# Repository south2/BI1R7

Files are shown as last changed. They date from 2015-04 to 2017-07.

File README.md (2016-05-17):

# body interaction vibrator development board

body interaction 1 board, revision 7

The *body interaction 1* is a tiny microcontroller board for building vibrating devices like (sex) toys. 
The vibration strength is controlled by motion. It is equipped with a radio module for wireless data transmission. 
The *body interaction 1* includes a LiPo battery and a capsuled vibration motor. 
Supports the Arduino IDE and Codebender.

*body interaction 1* is small, cheap and you can start at once. You can program the board with the Arduino software (IDE) or in a web browser (eg. codebender). A demo sketch is already uploaded to the board. Download 3D cases from [Thingiverse](http://www.thingiverse.com), print them, assemble the *body interaction 1* and have fun! Or invent your own toy using 3d modelling software.

#### More technical staff
*body interaction 1* has a Atmel Attiny84 on board, a LiPo charger (via USB) and a LiPo battery. The encapsuled vibration motor is controlled with PWM, though you can vary the vibration strength as needed. There are two additional I/O ports which can be used for other sensors or actuators. Programming is done with an ISP interface (2×3 pole header). The board has BMA020 accelerometer and a RFM12B (915 or 868 Mhz) radio module. Size: approx. 20x36mm. Open Source Hardware. Supports the Arduino IDE as well as codebender.
You need an ISP programmer (eg. USB tiny ISP) for uploading *new* programs (sketches) to the *body interaction 1*. There are two options for the wireless transmission chip. You can select 868 MHz (EU) or 915MHz (US, Australia) radio module.

Blog & How-to's: [www.bodyinteraction.com](http://www.bodyinteraction.com)

Download the [Quick start guide](https://projectbodyinteraction.files.wordpress.com/2015/09/quickstartguide-bodyinteraction1.pdf)

3d models at [Thingiverse](http://www.thingiverse.com/south/designs)

Construct your own with the 3d modelling software [Tinkercad](https://www.tinkercad.com/users/3N2Od7pDF0x-bodyinteraction)

Arduino example sketch at [codebender](https://codebender.cc/embed/sketch:96042#p5_fin.ino)

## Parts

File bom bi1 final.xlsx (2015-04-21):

Partlist
2015-03-27 | BI1R7.zip
Part | Value | Device | Package | Description (Package size in inch) | Ordered from | Order-ID | Manufacturer Part No | Remarks
BMA020 |  | BMA020 | LBA-12 | BOSCH033 (BMA020) mobile phone chips gravity acceleration sensor | Aliexpress |  |  | ordered via aliexpress | http://www.aliexpress.com/snapshot/285585944.html
C1 | 0.1micro | C-EUC0603K | C0603K | Multilayer Ceramic Capacitors MLCC - SMD/SMT 0201 0.1pF 25volts C0G +/-0.1pF | Mouser | 81-GRM0335C1ER10BA1D | GRM0335C1ER10BA01D |  | http://de.mouser.com/ProductDetail/Murata/GRM0335C1ER10BA01D/
C2 | 0.1micro | C-EUC0603K | C0603K | Multilayer Ceramic Capacitors MLCC - SMD/SMT 0201 0.1pF 25volts C0G +/-0.1pF | Mouser | 81-GRM0335C1ER10BA1D | GRM0335C1ER10BA01D |  | http://de.mouser.com/ProductDetail/Murata/GRM0335C1ER10BA01D/
C3 | 1micro | CAP0603-CAP | 0603-CAP | Multilayer Ceramic Capacitors MLCC - SMD/SMT CAP, MLCC, 0201, 50V C0G 1pF 0.25pF tol | Mouser | 963-UMK063CG010CT-F | UMK063CG010CT-F |  | http://de.mouser.com/ProductDetail/Taiyo-Yuden/UMK063CG010CT-F/
C4 | 1micro | CAP0603-CAP | 0603-CAP | Multilayer Ceramic Capacitors MLCC - SMD/SMT CAP, MLCC, 0201, 50V C0G 1pF 0.25pF tol | Mouser | 963-UMK063CG010CT-F | UMK063CG010CT-F |  | http://de.mouser.com/ProductDetail/Taiyo-Yuden/UMK063CG010CT-F/
C7 | 0.1micro | CAP0603-CAP | 0603-CAP | Multilayer Ceramic Capacitors MLCC - SMD/SMT 0201 0.1pF 25volts C0G +/-0.1pF | Mouser | 81-GRM0335C1ER10BA1D | GRM0335C1ER10BA01D |  | http://de.mouser.com/ProductDetail/Murata/GRM0335C1ER10BA01D/
LED/CHARGE | ORANGE | LED0603 | LED-0603 | Standard LEDs - SMD GaP Orange | Mouser | 630-HSMD-C190 | HSMD-C190 |  | http://de.mouser.com/ProductDetail/Avago-Technologies/HSMD-C190/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
MICROCONTROLLER | Attiny84 | TINY24/44/84-SSU | SOIC14 | 8-bit Microcontrollers - MCU 8-bit 512B SRAM 20MHz 2.7-5.5V | Mouser | 556-ATTINY84-20SSU | ATTINY84-20SSU |  | http://de.mouser.com/Search/ProductDetail.aspx
MBR120* | F | MBR120ESF | SOD-123_MINI-SMA | Schottky Diodes & Rectifiers 1A 20V | Mouser | 863-MBR120ESFT1G (https://de.mouser.com/Search/ProductDetail.aspx) | MBR120ESFT1G (https://de.mouser.com/Search/ProductDetail.aspx)
M*1N02 |  | MGSF1N02LT1G | SOT23 | MOSFET N-CH 20V 750MA SOT23 (Transistor) | digikey | MGSF1N02LT1GOSCT-ND | MGSF1N02LT1G (http://www.digikey.de/product-detail/en/MGSF1N02LT1G/MGSF1N02LT1GOSTR-ND/919442) |  | http://de.mouser.com/Search/ProductDetail.aspx
R1 | 10K | R-EU_R0603 | R0603 | Thick Film Resistors - SMD 1/10watts 10Kohms 1% | Mouser | 660-RK73H1JTTD1002F | RK73H1JTTD1002F |  | https://de.mouser.com/Search/ProductDetail.aspx
R2 | 10K | R-EU_R0603 | R0603 | Thick Film Resistors - SMD 1/10watts 10Kohms 1% | Mouser | 660-RK73H1JTTD1002F | RK73H1JTTD1002F |  | https://de.mouser.com/Search/ProductDetail.aspx
R4 | 15 | R-EU_R0603 | R0603 | Thick Film Resistors - SMD 1/10watts 15ohms 1% | Mouser | 660-RK73H1JTTDD15R0F | RK73H1JTTDD15R0F |  | https://de.mouser.com/Search/ProductDetail.aspx
R6 | 50k | R-EU_R0603 | R0603 | Thick Film Resistors - SMD 1/10watts 49.9Kohms | Mouser | 660-RK73H1JTTD4992F | RK73H1JTTD4992F |  | https://de.mouser.com/Search/ProductDetail.aspx
R9 | 470 | R-US_R0603 | R0603 | Thick Film Resistors - SMD 0603 470ohms 5% Tol | Mouser | 667-ERJ-3GEYJ471V | ERJ-3GEYJ471V |  | https://de.mouser.com/Search/ProductDetail.aspx
RFM12B - RF module the 868 MHz (70x) or 915 MHz (30x) versions will be soldered on the bottom side |  |  |  | octamex | FM-RFM12B-868-S1 | RFM12B-868-S1 | 868 MHz for Europe, select S1 or S2 type, both are ok
 |  |  |  | Sparcfun | WRL-12031 |  | 915 MHz for US and Australia, select S1 or S2 type, both are ok | https://www.sparkfun.com/products/12031
SWITCH | ON | SWITCH-SPDTSMD2 | SWITCH-SPDT-SMD | SWITCH SLIDE SPDT 12V 100MA GW | digikey | 401-2012-1-ND | AYZ0102AGRLC (http://www.digikey.de/product-detail/en/AYZ0102AGRLC/401-2012-2-ND/1640108) |  | http://de.mouser.com/Search/ProductDetail.aspx
U2 | MAX | MAX1555 | SOT23-5 | Battery Management Dual USB/AC 1-Cell Li+ Battery Charger | Mouser | 700-MAX1555EZK+T | MAX1555EZK+T |  | http://de.mouser.com/Search/ProductDetail.aspx
USB |  | USB-MICROB | USB-MICROB | USB Connectors MICRO B RECEPT RA SMT BTTM MNT | Mouser | 798-ZX62-B-5PA11 | ZX62-B-5PA(11) |  | https://de.mouser.com/Search/ProductDetail.aspx
LiPo connection on board |  |  |  | JST CONN HEADER SH 2POS SIDE 1MM TIN | digikey | 455-1802-1-ND
LiPo JST SH Connector | please connect LiPo cables with JST SH connector (2 crimp terminals and housing) |  |  | CONN HOUSING SH 2POS 1MM WHITE | digikey | 455-1392-ND
 |  |  |  | CONN TERM SH CRIMP 28-32AWG TIN | digikey | 455-1561-1-ND
LiPo
Motor connection on board |  |  |  | JST CONN HEADER SH 2POS SIDE 1MM TIN | digikey | 455-1802-1-ND
motor JST SH Connector | please connect motor cables with JST SH connector (2 crimp terminals and housing) |  |  | CONN HOUSING SH 2POS 1MM WHITE | digikey | 455-1392-ND
 |  |  |  | CONN TERM SH CRIMP 28-32AWG TIN | digikey | 455-1561-1-ND
Motor |  |  |  | 7mm 1.5V Vibration motor |  | 306-108 |  |  | https://catalog.precisionmicrodrives.com/order-parts/product/306-108-7mm-vibration-motor-25mm-type
ISP Connector - do NOT solder
ISP |  | MA03-2S | MA03-2-0.8 | CONN HEADER 6POS .100 R/A 15AU | digikey | 609-3343-ND | 68021-206HLF |  | http://www.digikey.com/product-search/en?WT.z_header=search_go&lang=en&site=us&x=0&y=0&formaction=on

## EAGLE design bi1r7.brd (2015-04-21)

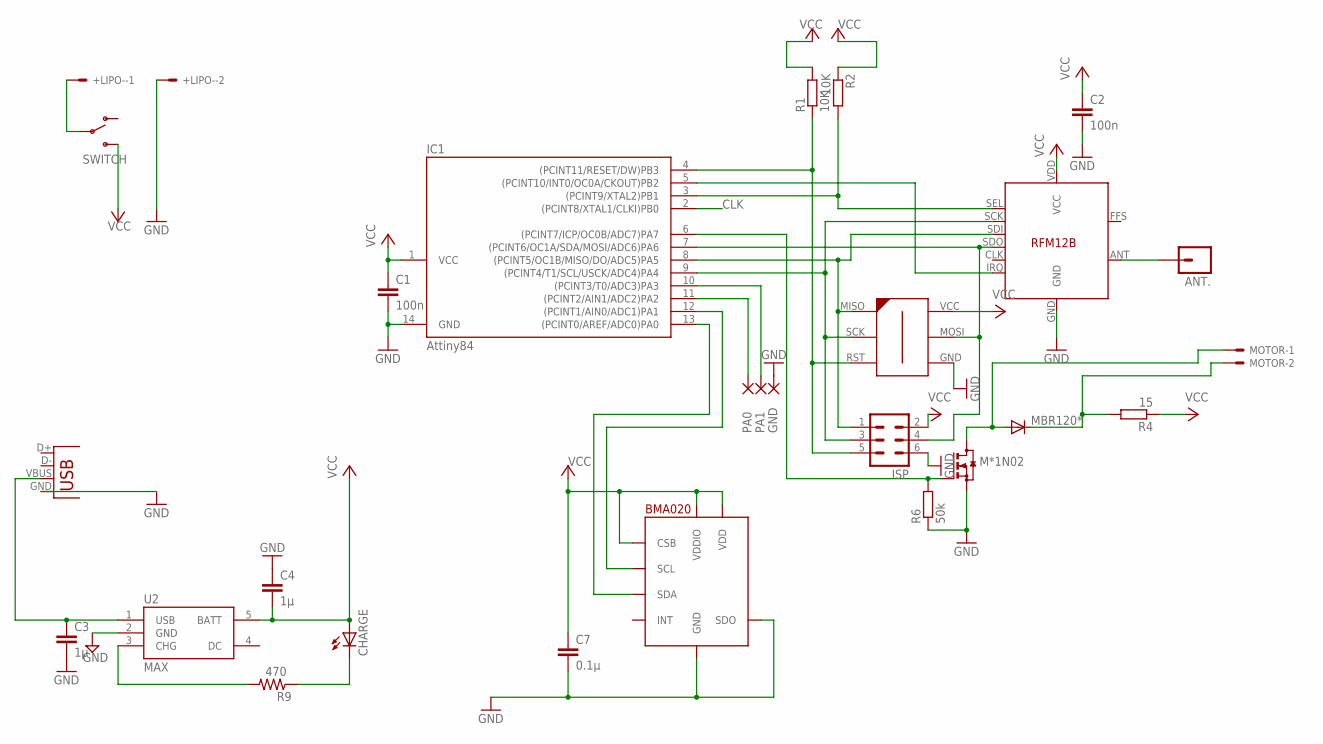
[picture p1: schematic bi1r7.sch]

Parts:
+LIPO-: SM02B-SRSS-TB
ANT.: M01PTH; 1X01
BMA020: BMA020; LBA-12
C1, C2: 100n; C0603K
C3, C4: 1µ; 0603-CAP
C7: 0.1µ; 0603-CAP
CHARGE: LED0603; LED-0603
GND: SMD2; SMD1,27-2,54
IC1: Attiny84; SOIC14
ISP: MA03-2S; MA03-2-0.8
M*1N02: BSS123; SOT23
MBR120*: CGRM4001-G; SOD-123_MINI-SMA
MOTOR: SM02B-SRSS-TB
PA0, PA1: SMD2; SMD1,27-2,54
R1, R2: 10K; R0603
R4: 15; R0603
R6: 50k; R0603
R9: 470; R0603
RFM12B: RFM12B
SWITCH: SWITCH-SPDTSMD2; SWITCH-SPDT-SMD
U2: MAX; SOT23-5
U$2: AVR-ISP-6-EDGE; 6PAD_ISP
USB: USB-MICROB

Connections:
CLK: IC1.2 ((PCINT8/XTAL1/CLKI)PB0)
GND: +LIPO-.2, BMA020.P$3 (GND), BMA020.P$7 (SDO), C1.2, C2.2, C3.2, C4.1, C7.2, GND.1, IC1.14 (GND), ISP.6, M*1N02.2 (S), R6.1, RFM12B.GND, U2.2 (GND), U$2.GND, USB.GND
LED: BMA020.P$8 (SDA), IC1.13 ((PCINT0/AREF/ADC0)PA0)
unnamed: IC1.4 ((PCINT11/RESET/DW)PB3), ISP.5, R1.1, U$2.RST
unnamed: IC1.3 ((PCINT9/XTAL2)PB1), R2.2, RFM12B.SEL
unnamed: ANT..1, RFM12B.ANT
unnamed: IC1.9 ((PCINT4/T1/SCL/USCK/ADC4)PA4), ISP.3, RFM12B.SCK, U$2.SCK
unnamed: IC1.8 ((PCINT5/OC1B/MISO/DO/ADC5)PA5), ISP.1, RFM12B.SDI, U$2.MISO
unnamed: IC1.7 ((PCINT6/OC1A/SDA/MOSI/ADC6)PA6), ISP.4, RFM12B.SDO, U$2.MOSI
unnamed: IC1.5 ((PCINT10/INT0/OC0A/CKOUT)PB2), RFM12B.IRQ
unnamed: IC1.6 ((PCINT7/ICP/OC0B/ADC7)PA7), M*1N02.1 (G), R6.2
unnamed: IC1.10 ((PCINT3/T0/ADC3)PA3), PA1.1
unnamed: IC1.11 ((PCINT2/AIN1/ADC2)PA2), PA0.1
unnamed: BMA020.P$6 (SCL), IC1.12 ((PCINT1/AIN0/ADC1)PA1)
unnamed: M*1N02.3 (D), MBR120*.A, MOTOR.1
unnamed: MBR120*.C, MOTOR.2, R4.2
unnamed: C3.1, U2.1 (USB), USB.VBUS
unnamed: +LIPO-.1, SWITCH.2
unnamed: CHARGE.C, R9.1
unnamed: R9.2, U2.3 (CHG)
VCC: BMA020.P$2 (VDD), BMA020.P$5 (CSB), BMA020.P$9 (VDDIO), C1.1, C2.1, C4.2, C7.1, CHARGE.A, IC1.1 (VCC), ISP.2, R1.2, R2.1, R4.1, RFM12B.VDD (VCC), SWITCH.3 (S), U2.5 (BATT), U$2.VCC

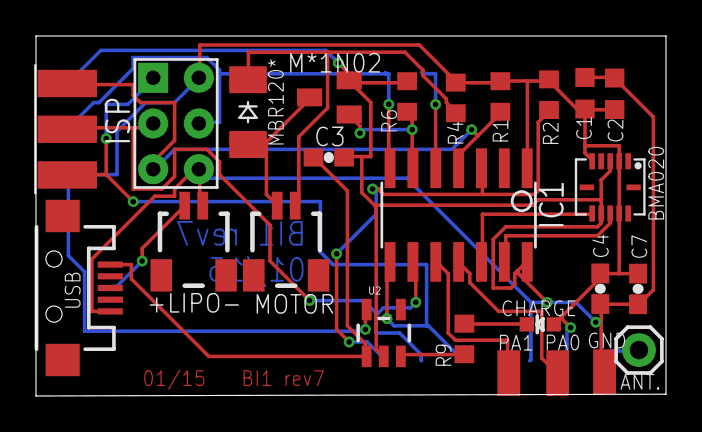
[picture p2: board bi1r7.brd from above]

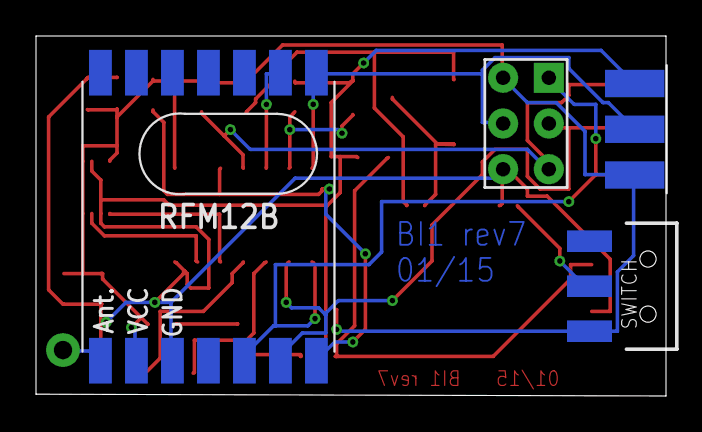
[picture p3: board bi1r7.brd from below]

Board: 4 copper layers, 35.0 x 20.0 mm, 27 parts (2 on the bottom side), 20 nets.

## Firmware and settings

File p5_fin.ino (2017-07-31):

/* body interaction 1 script "p5"
   hardware: body interaction 1 board
   www.bodyinteraction.com
   info@bodyinteraction.com

   The body interaction 1 board is based on the Jeenode Micro that uses for the communication the Hope RFM12b. In the context
   of wireless communication each body interaction board is a node.
   Motion is measured with the accelerometer BMA020. A vibration motor is driven with a simple  with transitor and diode.

   The script reads data from the accelorometer. Depending of the measured motion a vibration motor is speed up or slowed
   down. (Slow motion = reduce viration motor speed, fast motion = speed up). When the measured motion changes the motion data are send out and can be received by other BI1. In addition you can
   use a jeenode to receive the data and send them to a PC for further processing.
   At the same time this script listen to other body interaction boards which send their motion data
   to all listening nodes. When the measured motion of other body interaction board are different from the motion
   measured by this script, the vibration motor is adjusted (speed up or slowed down). So two or more body interaction boards
   can influence each other and syncronize after some time.

   There are 3 states (modes): active, pause, sleep

   active: In the active state the body interaction board behave like described above. When there is no motion and other boards don't
   send motion data the vibration motor is set to low vibration. After some time the state changes to pause.

   pause: In the pause state the vibration motor is off. But the body interaction board still listen to other body interaction board.
   If it receives motion data from an other board or wehn to motion of the borad itself changes the state is changed to active.
   If nothing happens the state is changes to sleeping after some time.

   sleeping: The body interaction board is set to sleep modus and saves battery power. After some tiem the board wakes up
   and read out the motion data. If the board is moved the state is changed to active.

   This code is in the public domain.
  */
#include <JeeLib.h> // Jeelab Library
#include <avr/sleep.h> // sleep module
ISR(WDT_vect)
{
	Sleepy::watchdogEvent();
}

// states
const int active = 2;
const int pause = 1;
const int sleeping = 0;
int state = active; // current state

const int myId = 3; //Id number of this node
const int myNetwork = 20; // number of the network, only nodes in the same network can communicate with one another

// constants are compared with calcDiff()
const int sensorNoise = 20;
const int diffLowSpeed = 35; //v1: 70
const int maxMotorSpeed = 255; //255
const int decreaseStep = 20; //v1: 20
const int wakeUpDiff = 20; //wake up from sleep state
const int motorPin = 3;  // pin number for driving the node with PWM

const int sendMax = 8;
const int sendNormal = 3;

PortI2C myBus (1); // the accelerometer is connected with I2C port number 1 (ports are a convention in the JeeLib)

GravityPlug sensor (myBus); // the accelerometer is named as "sensor"

// Jeelib timer
MilliTimer sendTimer; // sending data is allowed when timer fires
MilliTimer readGTimer; // when timer fires gravity (motion) data should be read
MilliTimer pauseTimer; // when timer fires BI1 board can go into state pause
MilliTimer sleepTimer; // when timer fires BI1 board can go into stat sleep

int payload[] = {diffLowSpeed, state}; // payload is an array send to other BI1

//global variables
int p1[3] = {0, 0, 0}; // Motion data and time=1 in (x,y,z) direction
int p0[3] = {0, 0, 0}; // Motion data and time=0 in (x,y,z) direction
int d[3] = {0, 0, 0}; // differnce between time=1 and time=0 in (x,y,z) direction

// character to integer casting
int c2i(char c)
{
	return (((int)c) + 127);
}
// integer to character casting
char i2c (int i)
{
	return ((char)i - 127);
}

// heuristic function for calculating the motion difference between time=1 and time=0
// returns the maximum difference from each (x,y,z) direction
int calcDiff()
{
	int diff;
	d[0] = abs(p1[0] - p0[0]);
	d[1] = abs(p1[1] - p0[1]);
	d[2] = abs(p1[2] - p0[2]);
	diff = max(d[0], d[1]);
	diff = max(diff, d[2]);
	return diff;
}

// read out the acceleromter data
// function return the difference based on calcdiff()
int gravityRead ()
{
	const int* p = sensor.getAxes();
	int difference;
	p0[0] = p1[0]; // store old data in p0[] (time = 0)
	p0[1] = p1[1];
	p0[2] = p1[2];
	p = sensor.getAxes(); // read out sensor
	p1[0] = p[0]; // store new data in p1[] (time = 1)
	p1[1] = p[1];
	p1[2] = p[2];
	difference = calcDiff();
	return difference;
}


boolean shouldSend()   // interval between data sending
{
	sendTimer.poll(100); // 100 millisecond = 0.1 second (1 second = 1000 milliseconds)
}
boolean shouldReadG()   // intervall between motion measurement
{
	readGTimer.poll(300); // approx 0.3 seconds
}
void resetReadGTimer()   // reset timer
{
	readGTimer.set(0);
}
boolean shouldPause()  // interval between last measured motion change and changing state to pause (motor off)
{
	pauseTimer.poll();
}
boolean armPauseTimer()  // init timer
{
	pauseTimer.set(1000 * 5 * 2); // aprox 10 seconds
}
boolean shouldSleep()   // interval between entering pause state and changing to sleep state
{
	sleepTimer.poll();
}
void armSleepTimer()   // init timer
{
	sleepTimer.set(1000 * 5 * 4); // approx 10 seconds
}



int diff_t0; // last measured difference in motion
int diff; // variable for current difference in motion

int repeatSendN; // repeat data send n times
boolean received; // boolean variable true when data received

/* in this loop the following tasks are done:
   1. measure motion data
   2. change vibration motor speed according to motion data
   3. change states
   4. listen to the receiver
   5. change vibration motor speed if motion data from othe body interaction 1 (BI1) are received
*/

void loop()
{
	if (shouldReadG())
	{
		diff = gravityRead(); //measure motion data
		if (state == pause && diff < diffLowSpeed) diff = 0; // set variable diff to 0 when in pause state
		else   // motion detected: calculated diff, smoothing
		{
			if (diff + decreaseStep < diff_t0)
			{
				diff = max(diff_t0 - decreaseStep, diffLowSpeed);    // motion reduced
				state = active;
			}
			else diff = max((diff + diff_t0) / 2, diffLowSpeed);
			state = active; // motion increased
		}

		if (diff > diff_t0 + sensorNoise)
		{
			armPauseTimer();    // motion increased: reset pause timer
			repeatSendN = sendMax;
		}

		if (diff == diffLowSpeed && shouldPause())
		{
			state = pause;    // change to pause state
			diff = 0;
			armSleepTimer();
		}

		diff = min(maxMotorSpeed, diff); // measured motion (diff) becomes vibration motor speed, motor speed not about maximum

		analogWrite(motorPin, diff);  // set vibration motor speed; use variable diff

		payload[0] = i2c(diff); // prepare payload for sending, put diff in the first byte
	} //(shouldReadG())

	// sleep mode: stay in sleep state until motion is measured
	if (state == pause && shouldSleep()) // go into sleep state when in pause state for some time
	{
		delay(100);
		rf12_sleep(RF12_SLEEP); // set RFM12 module asleep and save battery
		delay(100);
		diff = gravityRead(); // check motion
		while (diff < wakeUpDiff) // if motion is less than treshold: fall asleep for approx 30 seconds
		{
			delay(100);
			Sleepy::loseSomeTime(30000); // now fall asleep
			delay(100); // needs some time to wake up
			diff = gravityRead(); //measure motion again
		}
		delay(100); // end of sleep state
		state = active; // go to active state
		armPauseTimer(); // reset timer
		resetReadGTimer();
		diff = diffLowSpeed; // set diff to "öow speed" - vibration motor will start to say hello
		diff_t0 = diffLowSpeed;
	}

	diff_t0 = diff; // go to next time cycle; current diff becomes old diff (time=0);

	// sending data
	if (shouldSend() && (repeatSendN > 0)) // check if data have to be send
	{
		if (rf12_canSend())   // check if no other radio is sending
		{
			rf12_sendStart(0, payload, sizeof payload); // send
			repeatSendN--; //  number of times to repeat sending is reduced by 1
		}
	}

	// listen to other body interaction 1 boards
	received = rf12_recvDone() && rf12_crc == 0; // call important rf12_recvDone() function, returns true if data are received
	if (received)
	{
		diff = c2i(rf12_data[0]); // received motion data are used to drive vibration motor
		// you could add code for smoothing the new motion data
		if (diff > -1)   // ignore -1 (measurement or transmission error)
		{
			diff = min(maxMotorSpeed, diff); // set motor speed to variable diff
			diff_t0 = diff;
			if (diff >= diffLowSpeed) analogWrite(motorPin, diff);
		}
	}
}


void setup()
{
	//Serial.begin(115200);
	//Serial.println("\n[body interaction 1 script ""p1""]");
	rf12_initialize(myId, RF12_868MHZ, myNetwork); // init RFM12 module; for some countries (eg. US) use RF12_915MHZ
	armPauseTimer();
	repeatSendN = sendNormal;
}

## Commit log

2015-04-21 BRD and SCH and BOM added
    [bi1r7.brd, bi1r7.sch, bom bi1 final.xlsx]
2017-07-31 code
    added Arduino code

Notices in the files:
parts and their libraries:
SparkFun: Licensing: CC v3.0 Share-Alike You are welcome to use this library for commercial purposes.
